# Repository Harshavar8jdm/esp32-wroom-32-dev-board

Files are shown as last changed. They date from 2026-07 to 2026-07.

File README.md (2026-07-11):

# ESP32-WROOM-32 Custom Development Board
**Designed by HTronics (Harsha Ganesh)**



A custom, breadboard-friendly development board for the ESP32-WROOM-32 module. This board features a modern USB-C interface, reliable serial communication via the CH340C, and an automatic bootloader entry circuit for seamless flashing.

</div>

---

## 📸 Project Showcase

### 3D Renders
<p align="center">
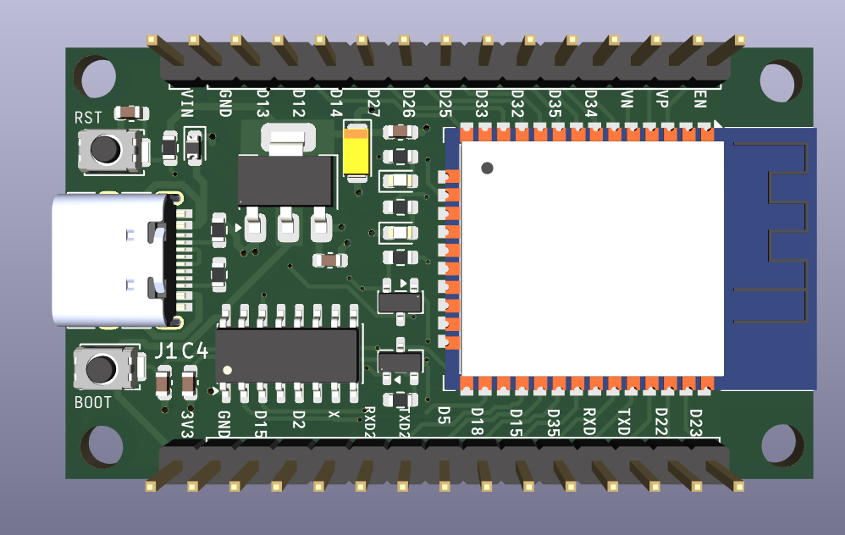
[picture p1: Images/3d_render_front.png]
3D Render Front
  
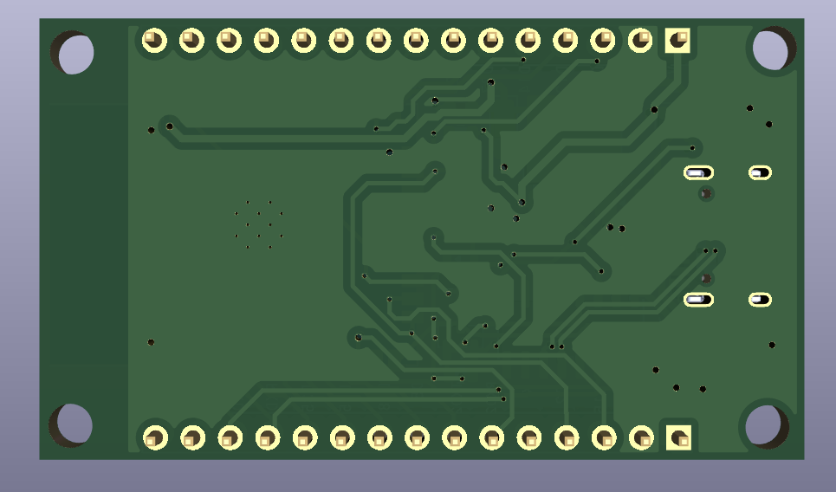
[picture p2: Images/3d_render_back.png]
3D Render Back
  
</p>

### PCB Layout & Schematic
<p align="center">
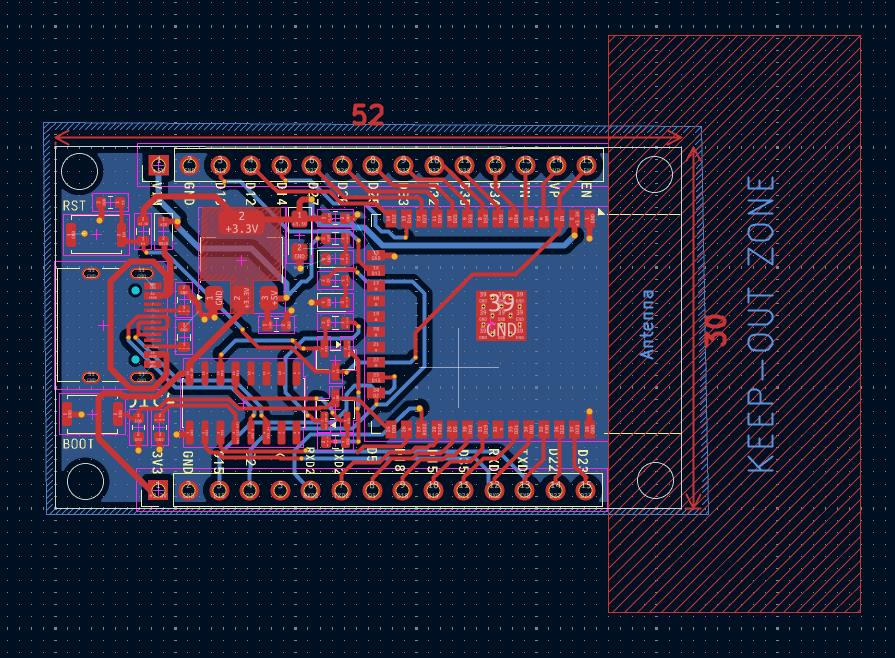
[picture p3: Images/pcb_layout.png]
PCB Layout
  
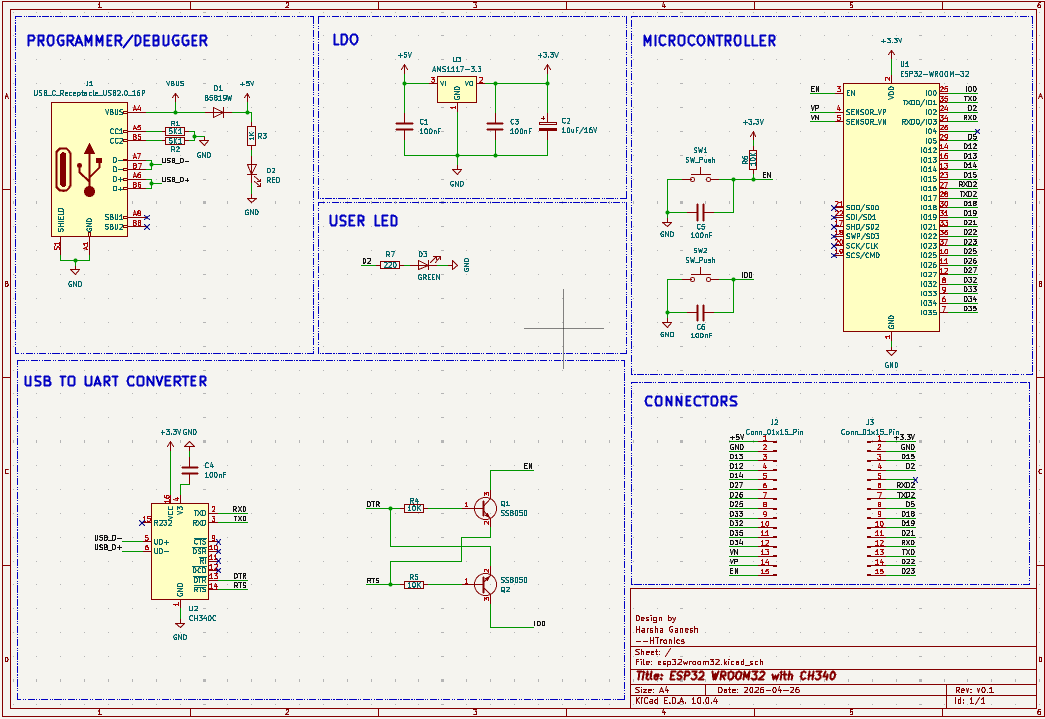
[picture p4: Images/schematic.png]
Schematic
  
</p>

---

## ✨ Key Features

* **Modern Connectivity:** USB 2.0 Type-C receptacle with 5.1kΩ pull-down resistors on the CC lines, ensuring compatibility with standard Type-A to Type-C and Type-C to Type-C cables.
* **Auto-Programming Circuit:** Built-in two-transistor (SS8050) auto-reset circuit driven by DTR/RTS lines. No need to hold the "BOOT" button to flash firmware.
* **Robust Power Delivery:** Uses the AMS1117-3.3 LDO to step down 5V VBUS to a stable 3.3V for the ESP32, paired with 100nF and 10uF decoupling capacitors. Includes a B5819W Schottky diode for back-power protection.
* **USB-to-UART:** CH340C bridge provides reliable serial communication without requiring an external crystal oscillator.
* **User I/O:** Includes standard EN (Reset) and IO0 (Boot) tactile switches, a dedicated Red power LED, and a Green user LED mapped to GPIO 2.
* **Breadboard Friendly:** 2x15 pin headers break out all essential ESP32 GPIOs, strapping pins, and power rails.

---

## 🛠️ Hardware Overview & Schematic Sections

### 1. Power Supply (`AMS1117-3.3`)
The board takes 5V input from the USB-C VBUS line. A B5819W reverse-polarity protection diode prevents current from feeding back into the host device. The AMS1117-3.3 low-dropout regulator supplies up to 1A of 3.3V power, more than sufficient for the ESP32's RF transmission peaks. 

### 2. USB-to-UART Bridge (`CH340C`)
The CH340C handles USB data enumeration. 
* **Driver Note:** If you are using Linux (e.g., Fedora, Ubuntu), the CH340 driver is already built directly into the kernel—making it truly plug-and-play without any manual DNF/APT installations. Windows and macOS users may need to install the official WCH drivers.

### 3. Auto-Reset Circuit (`SS8050 Transistors`)
The CH340C toggles the `DTR` and `RTS` pins during the firmware upload sequence. The two SS8050 NPN transistors translate these signals into the precise timing sequence required to pull `EN` (Reset) low while `IO0` is held low, putting the ESP32 into flash mode automatically.

---

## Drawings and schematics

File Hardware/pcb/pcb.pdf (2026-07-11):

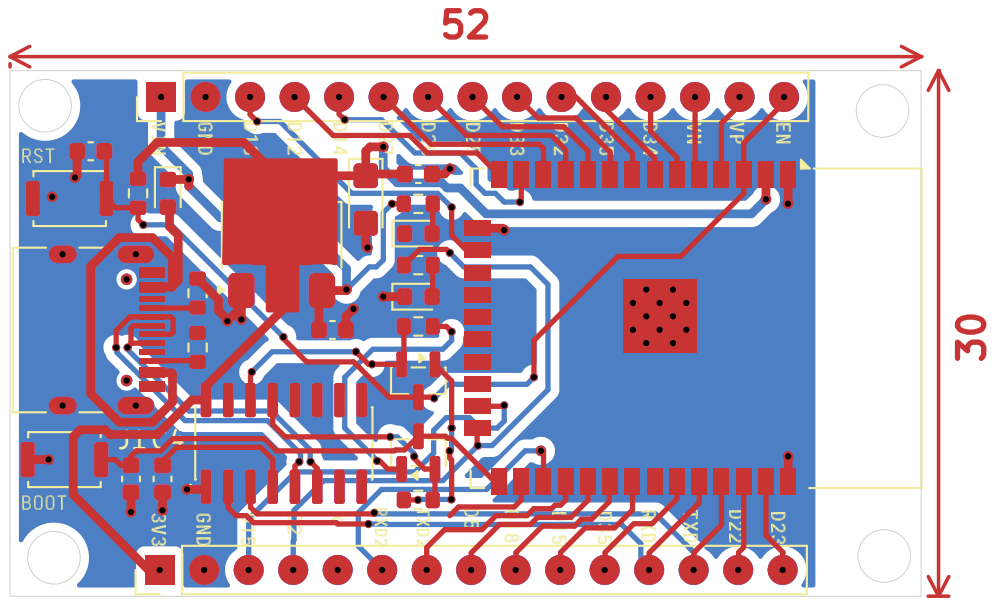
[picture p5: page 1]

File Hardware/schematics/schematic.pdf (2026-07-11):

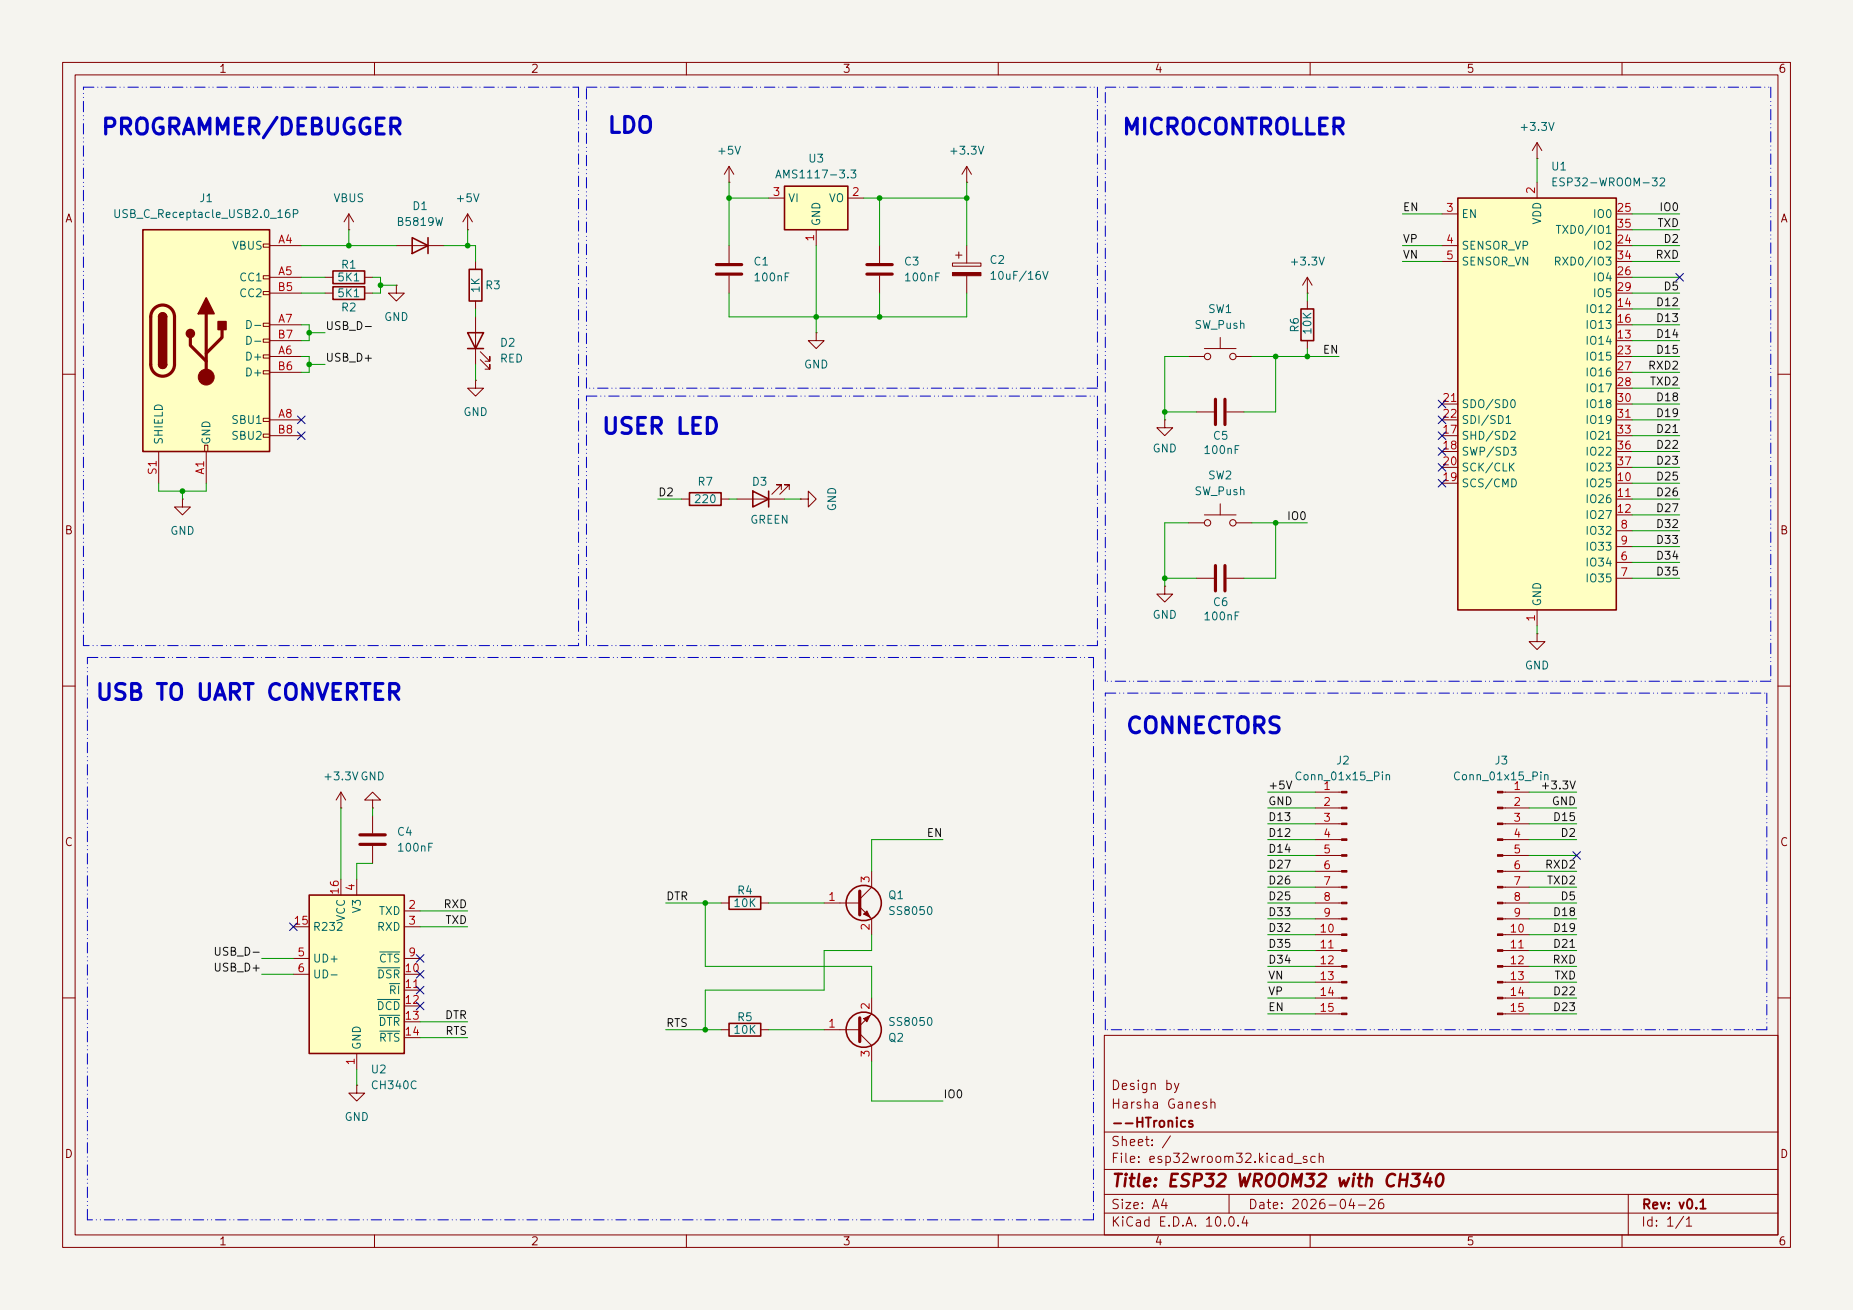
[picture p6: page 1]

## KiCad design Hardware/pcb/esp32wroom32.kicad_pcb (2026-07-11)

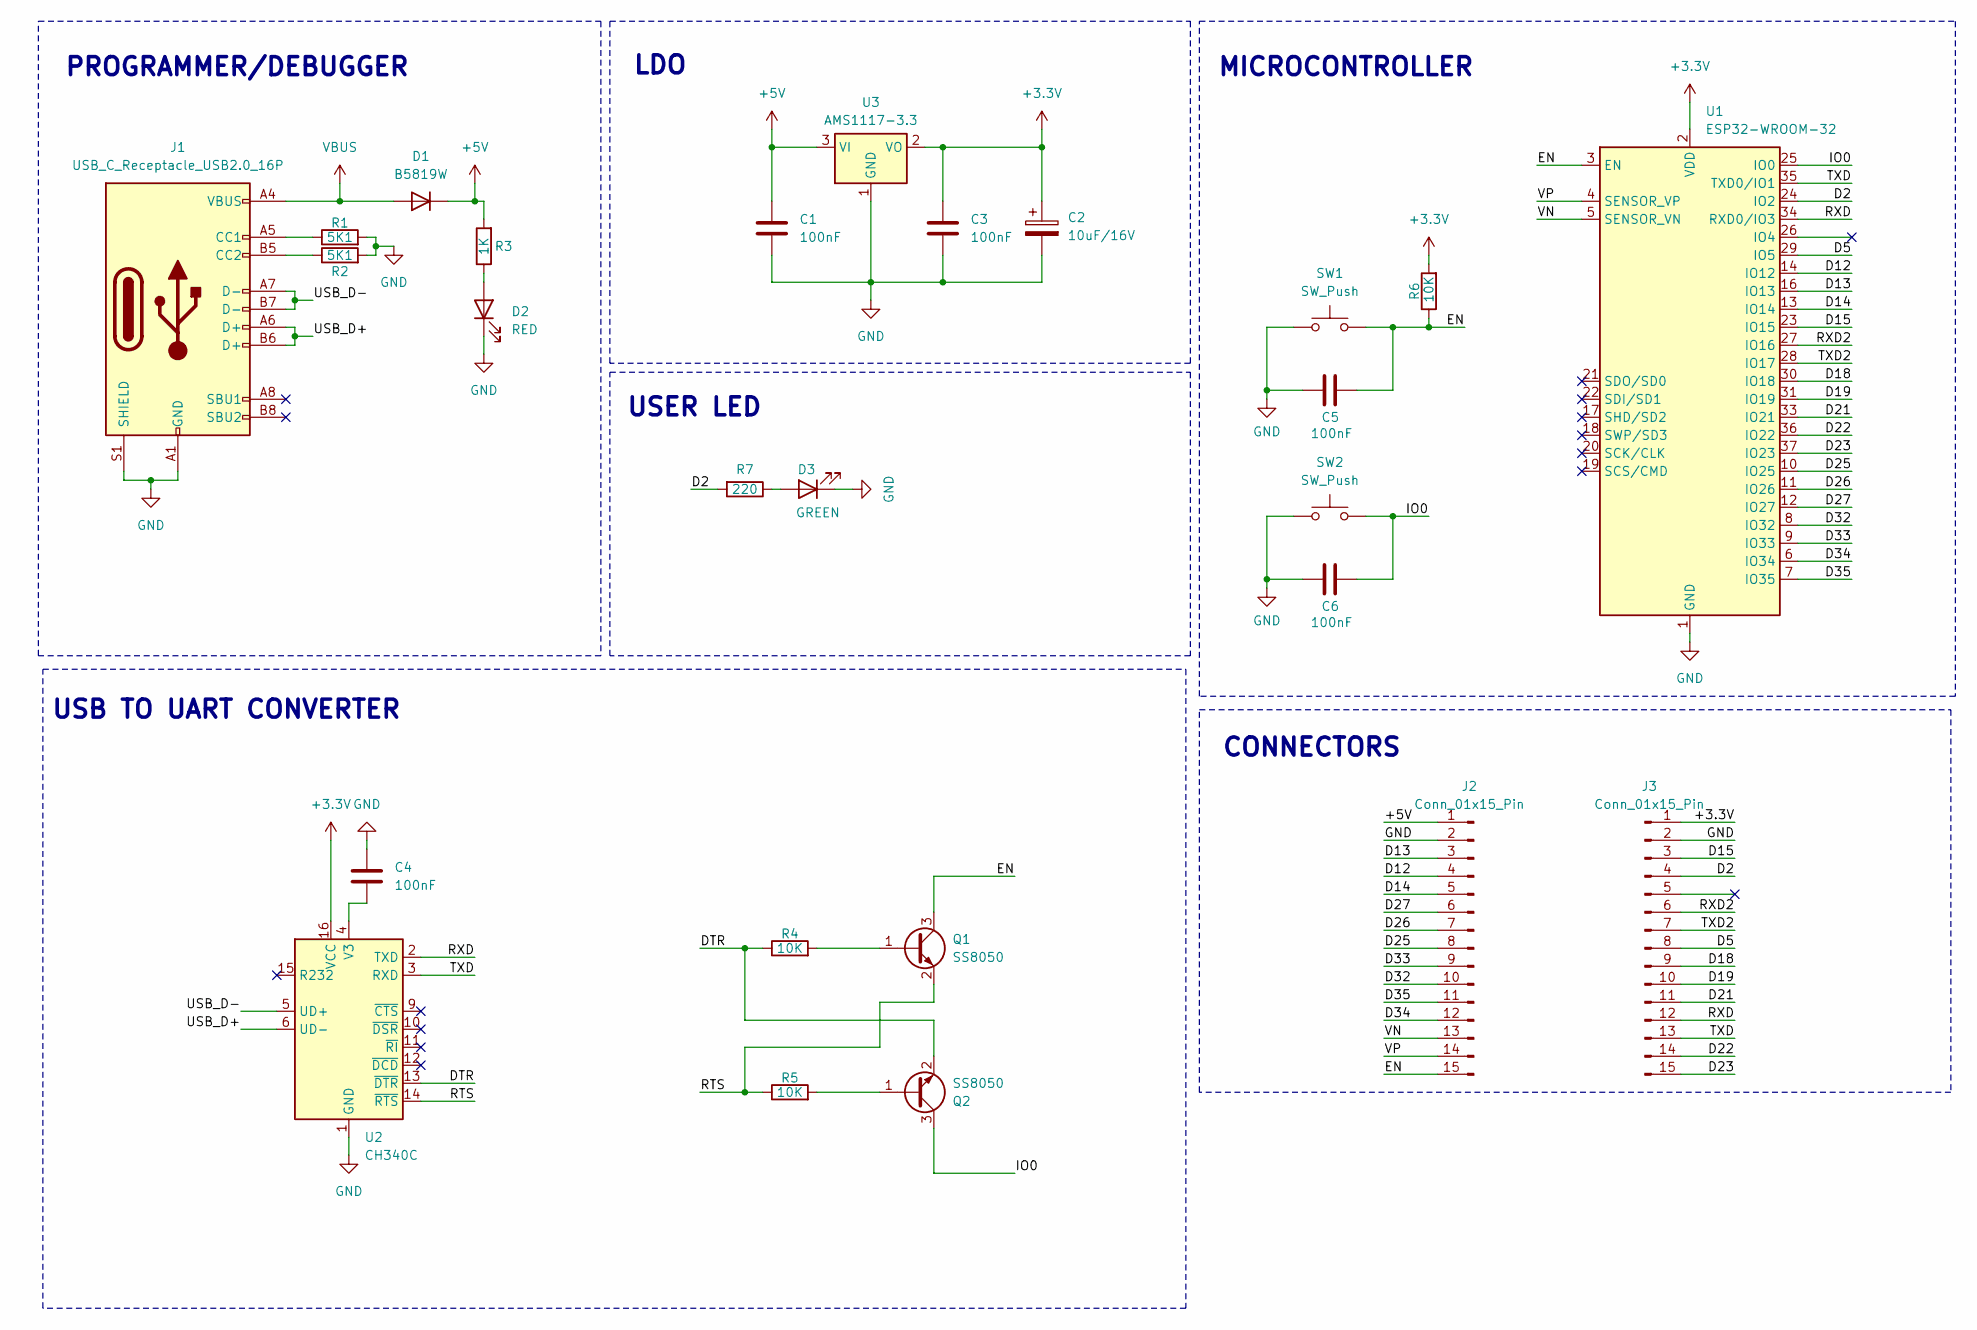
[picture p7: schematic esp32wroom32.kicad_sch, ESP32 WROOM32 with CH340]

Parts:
C1, C3, C4, C5, C6: 100nF; C_0603_1608Metric
C2: 10uF/16V; CP_EIA-3216-10_Kemet-I
D1: B5819W; D_0603_1608Metric
D2: RED; LED_0603_1608Metric
D3: GREEN; LED_0603_1608Metric
J1: USB_C_Receptacle_USB2.0_16P; USB_C_Receptacle_HRO_TYPE-C-31-M-12
J2, J3: Conn_01x15_Pin; PinHeader_1x15_P2.54mm_Vertical
Q1, Q2: SS8050; SOT-23
R1, R2: 5K1; R_0603_1608Metric
R3: 1K; R_0603_1608Metric
R4, R5, R6: 10K; R_0603_1608Metric
R7: 220; R_0603_1608Metric
SW1, SW2: SW_Push; SW_Push_SPST_NO_Alps_SKRK
U1: ESP32-WROOM-32
U2: CH340C; SOIC-16_3.9x9.9mm_P1.27mm
U3: AMS1117-3.3; SOT-223-3_TabPin2

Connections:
+3.3V: C2.1, C3.1, J3.1, R6.2, U1.2 (VDD), U2.16 (VCC), U3.2 (VO)
+5V: C1.1, D1.1 (K), J2.1, R3.2, U3.3 (VI)
/D2: J3.4, R7.2, U1.24 (IO2)
/D5: J3.8, U1.29 (IO5)
/D12: J2.4, U1.14 (IO12)
/D13: J2.3, U1.16 (IO13)
/D14: J2.5, U1.13 (IO14)
/D15: J3.3, U1.23 (IO15)
/D18: J3.9, U1.30 (IO18)
/D19: J3.10, U1.31 (IO19)
/D21: J3.11, U1.33 (IO21)
/D22: J3.14, U1.36 (IO22)
/D23: J3.15, U1.37 (IO23)
/D25: J2.8, U1.10 (IO25)
/D26: J2.7, U1.11 (IO26)
/D27: J2.6, U1.12 (IO27)
/D32: J2.10, U1.8 (IO32)
/D33: J2.9, U1.9 (IO33)
/D34: J2.12, U1.6 (IO34)
/D35: J2.11, U1.7 (IO35)
/DTR: Q2.2 (E), R4.1, U2.13 (~DTR)
/EN: C5.1, J2.15, Q1.3 (C), R6.1, SW1.2, U1.3 (EN)
/IO0: C6.1, Q2.3 (C), SW2.2, U1.25 (IO0)
/RTS: Q1.2 (E), R5.1, U2.14 (~RTS)
/RXD: J3.12, U1.34 (RXD0/IO3), U2.2 (TXD)
/RXD2: J3.6, U1.27 (IO16)
/TXD: J3.13, U1.35 (TXD0/IO1), U2.3 (RXD)
/TXD2: J3.7, U1.28 (IO17)
/USB_D+: J1.A6 (D+), J1.B6 (D+), U2.6 (UD-)
/USB_D-: J1.A7 (D-), J1.B7 (D-), U2.5 (UD+)
/VN: J2.13, U1.5 (SENSOR_VN)
/VP: J2.14, U1.4 (SENSOR_VP)
GND: C1.2, C2.2, C3.2, C4.1, C5.2, C6.2, D2.1 (K), D3.1 (K), J1.A1 (GND), J1.A12 (GND), J1.B1 (GND), J1.B12 (GND), J1.S1 (SHIELD), J2.2, J3.2, R1.2, R2.2, SW1.1, SW2.1, U1.1 (GND), U1.15 (GND), U1.38 (GND), U1.39 (GND), U2.1 (GND), U3.1 (GND)
unnamed: D2.2 (A), R3.1
unnamed: D3.2 (A), R7.1
unnamed: J1.A5 (CC1), R1.1
unnamed: J1.B5 (CC2), R2.1
unnamed: Q1.1 (B), R4.2
unnamed: Q2.1 (B), R5.2
unnamed: C4.2, U2.4 (V3)
VBUS: D1.2 (A), J1.A4 (VBUS), J1.A9 (VBUS), J1.B4 (VBUS), J1.B9 (VBUS)

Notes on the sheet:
USER LED
CONNECTORS
PROGRAMMER/DEBUGGER
LDO
USB TO UART CONVERTER
MICROCONTROLLER

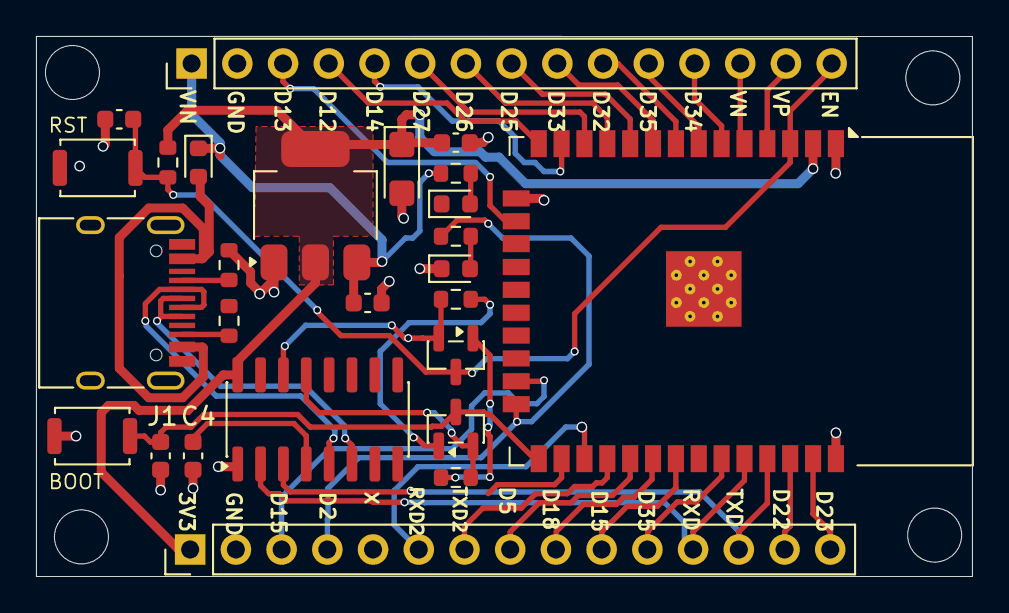
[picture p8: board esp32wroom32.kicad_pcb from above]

Board: 2 copper layers, 52.0 x 30.0 mm, 26 parts (0 on the bottom side), 41 nets.
